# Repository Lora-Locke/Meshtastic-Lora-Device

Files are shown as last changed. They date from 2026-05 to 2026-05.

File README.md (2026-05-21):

# 📡 LoRa Meshtastic Device — lora-locke

> *"What if you could send messages across kilometres of countryside, through forests, over hills,*  
> *with no phone signal, no internet, and no monthly bill?"*  
> That's exactly what this project does. Welcome to the mesh. 🌐

---

## What Is This?

This is an open source, 3D printed handheld LoRa Meshtastic communication node. It was designed and built as part of an **HNC Engineering Design (Unit 4001)** college project, but it turned into something genuinely useful — a pocket sized, off grid communication device that actually works in the real world.

The device is built around the **Seeed XIAO ESP32S3 + Wio SX1262 kit** from The Pi Hut, powered by dual hot swappable 18650 batteries, and housed in a custom designed 3D printed PLA enclosure with a detachable external SMA antenna. It talks to your phone over Bluetooth via the free **Meshtastic app**, and it can communicate with other Meshtastic nodes up to several kilometres away with absolutely no infrastructure whatsoever.

No towers. No SIM card. No subscription. Just radio waves and clever firmware.

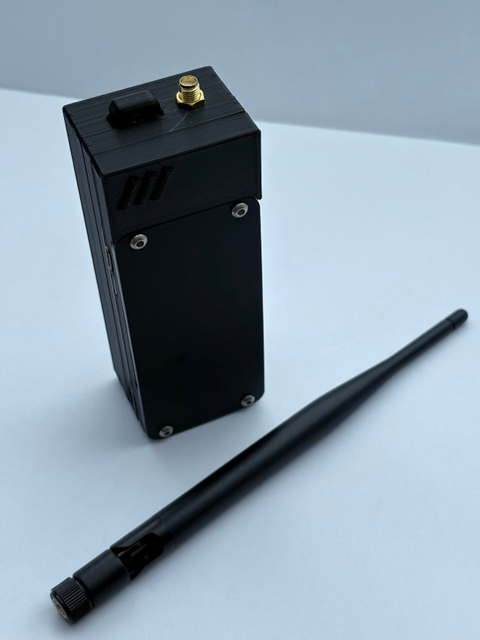
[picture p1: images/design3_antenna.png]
Device with antenna


---

## Why Does This Exist?

Good question. The short answer: because conventional communication infrastructure is fragile.

Mobile networks go down in emergencies. Rural areas have black spots the size of small countries. Events with thousands of people bring networks to their knees. And if you've ever tried to coordinate a hiking group in the middle of nowhere, you'll know that shouting really doesn't scale well beyond about 50 metres.

Meshtastic LoRa devices are a genuinely viable solution for:

- 🏔️ **Outdoor adventures** — hiking, mountain biking, wild camping, expeditions
- 🚨 **Emergency preparedness** — resilient backup comms when infrastructure fails
- 🎪 **Events and festivals** — coordinate teams without relying on congested networks
- 🌍 **Remote IoT deployments** — sensor networks in areas without connectivity
- 🔬 **Experimentation** — because building your own radio network is genuinely cool

This isn't a niche hobbyist toy. As infrastructure resilience becomes more important, decentralised mesh communication networks like Meshtastic represent a genuinely compelling backup safety communication solution. A handful of these devices distributed across a team or community creates a self healing, self extending communication network that requires nothing external to operate.

---

## How Does Meshtastic Work?

Meshtastic uses **LoRa (Long Range)** radio to create a mesh network. Each device acts as both a client and a router — when you send a message, nearby nodes receive it and automatically forward it along until it reaches its destination. The more nodes on the network, the further messages can travel.

Think of it like a game of Chinese whispers, except it actually works and the message arrives intact. 📨

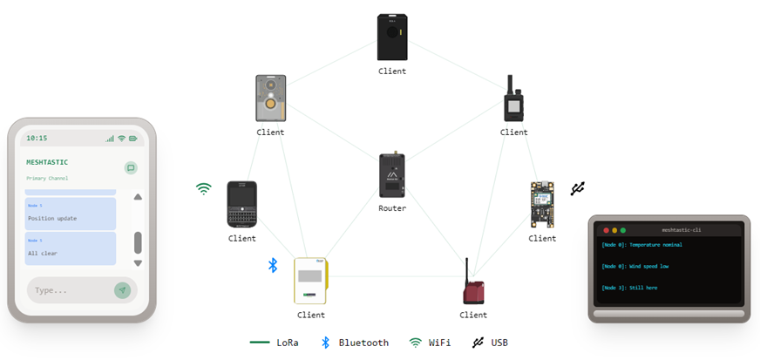
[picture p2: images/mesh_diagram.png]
Meshtastic Mesh Network Diagram


Each node operates on licence exempt frequencies (863–870 MHz in the UK, governed by Ofcom IR 2030 and ETSI EN 300 220), meaning anyone can use one legally without a radio licence.

For the full technical deep dive, the Meshtastic documentation is excellent:
👉 [meshtastic.org/docs/introduction](https://meshtastic.org/docs/introduction/)

---

## Features

- 📡 LoRa mesh communication via Meshtastic (862–930 MHz)
- 📱 Bluetooth app control — no screen needed, your phone is the interface
- 🔋 Dual 18650 hot swappable batteries — up to 30 hours runtime tested
- ⚡ USB-A power output — doubles as a power bank for your phone
- 🔌 USB-C and Micro USB charging inputs
- 🧲 Magnetic battery panel — tool free battery swaps in seconds, one cell at a time
- 📶 Detachable external SMA antenna — remove for pocket carry, attach for max range
- 🔴 Battery indicator LEDs — check charge status at a glance
- 🖨️ Fully 3D printable PLA enclosure
- 🌍 Completely open source hardware and software

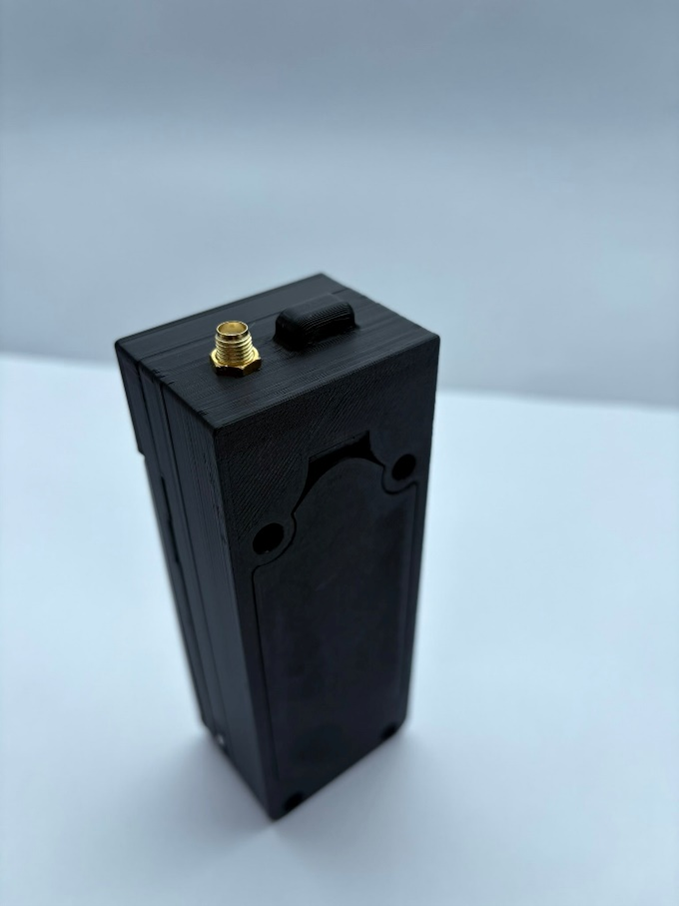
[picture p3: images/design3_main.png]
Device overview


---

## The Design Journey

This project went through three design iterations before landing on the final build. The full engineering process — including SolidWorks CAD models, structural force studies, design considerations across 15 criteria, and a weighted Pugh matrix evaluation — is documented in the accompanying college assignment report.

Here's the short version:

---

### Design 1 — The Brick 🧱

The first attempt. Functional, but at 105mm x 45mm x 50mm it was more portable safe than portable device. The battery board and LoRa module were stacked vertically inside the enclosure, which meant the height was completely impractical. Great as a fixed infrastructure node. Terrible in a pocket. Back to SolidWorks.

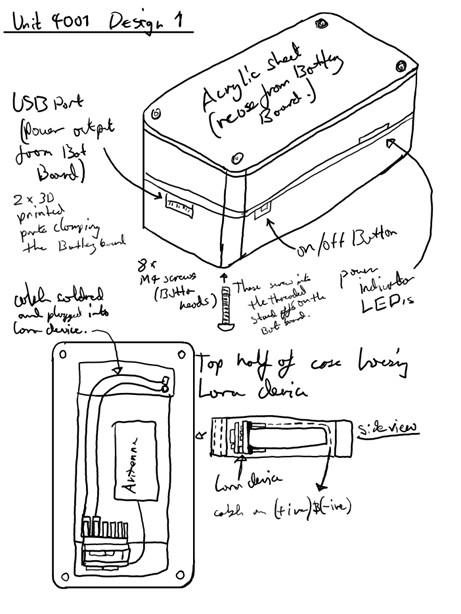
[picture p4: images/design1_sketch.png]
Design 1 Initial Sketch

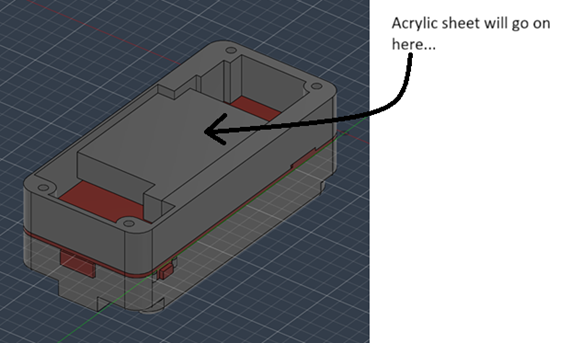
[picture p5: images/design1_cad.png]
Design 1 CAD


---

### Design 2 — Getting There 📐

Rotated the internal layout so the battery board and LoRa module sit side by side instead of stacked on top of each other. Result: 130mm x 50mm x 35mm — noticeably slimmer and much more natural to hold. A SolidWorks Simulation force study was run on this design to simulate drop loading and identify stress concentration points at the enclosure corners, which directly informed the geometry decisions in Design 3.

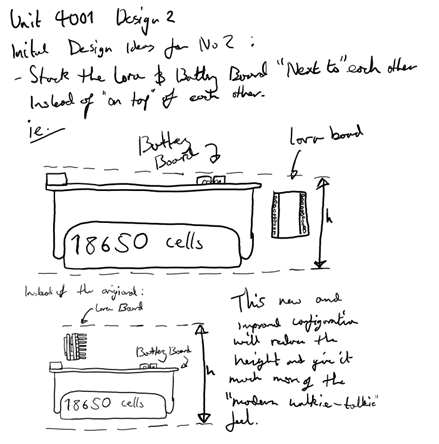
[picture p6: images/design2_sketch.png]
Design 2 Initial Sketch

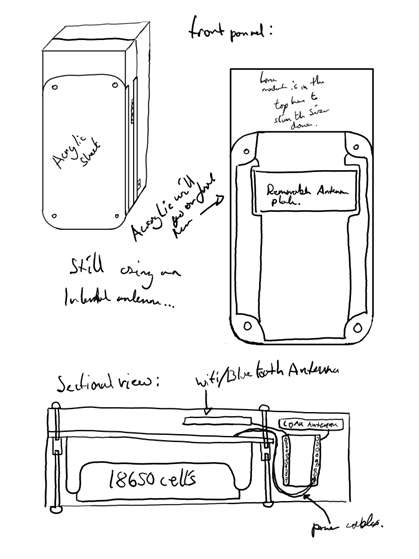
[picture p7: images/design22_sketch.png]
Design 2 Second Sketch

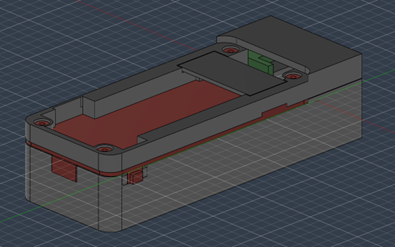
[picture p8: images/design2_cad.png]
Design 2 CAD

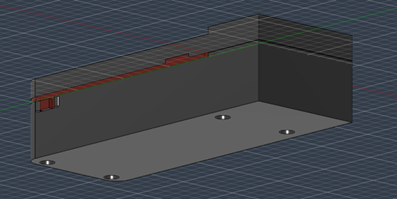
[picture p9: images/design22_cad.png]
Design 2 CAD View 2

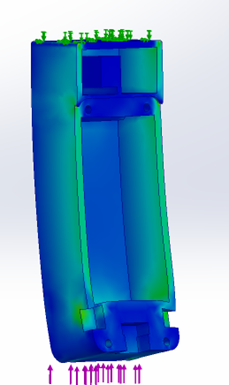
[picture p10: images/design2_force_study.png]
Design 2 Force Study

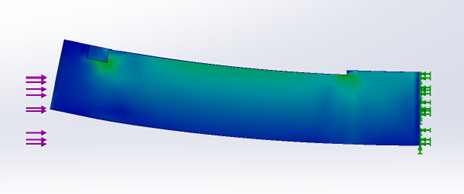
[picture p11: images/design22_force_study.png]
Design 2 Force Study View 2


---

### Design 3 — The One That Actually Works ✅

Same core dimensions as Design 2 but with two targeted improvements that make a significant real world difference:

1. **Detachable external SMA antenna** — remove it when pocketing the device, screw it on when you need maximum RF performance. Best of both worlds.
2. **Magnetic hot swap battery panel** — four neodymium magnets retain the battery cover, meaning you can swap 18650 cells in the field in seconds without any tools. One cell at a time, so you never even have to power the device down.

This is the design documented in this repository. This is the one you should build.

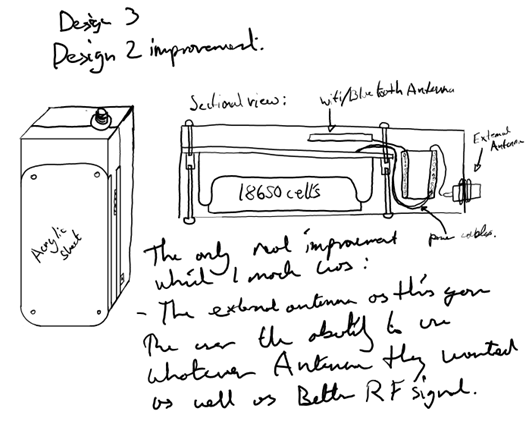
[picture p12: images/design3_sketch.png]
Design 3 Sketch

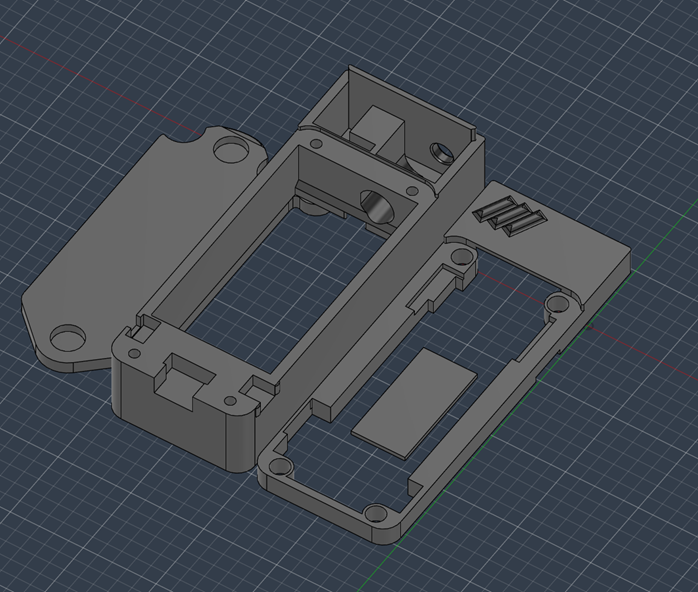
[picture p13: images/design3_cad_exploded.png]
Design 3 CAD Exploded

Design 3 Main Photo
Design 3 With Antenna
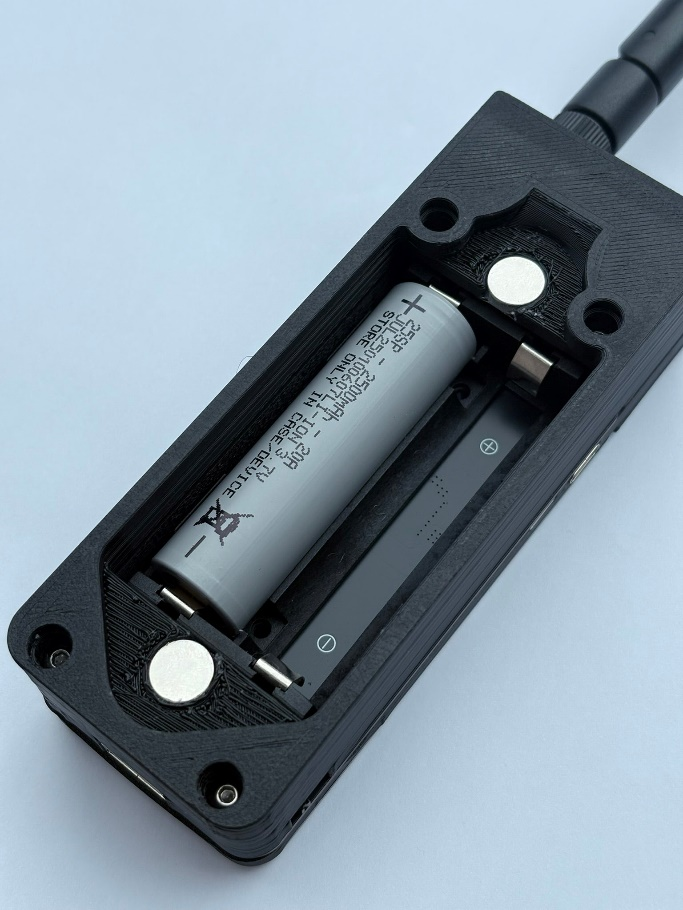
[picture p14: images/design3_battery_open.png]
Design 3 Battery Panel Open

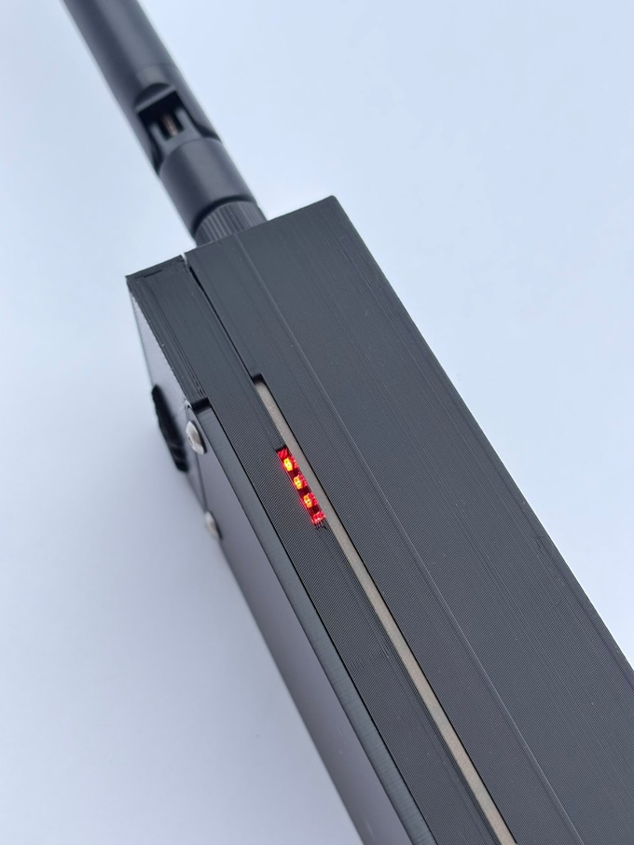
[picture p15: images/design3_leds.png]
Design 3 LED Battery Indicator

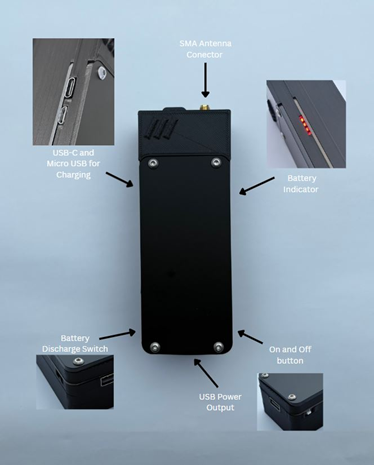
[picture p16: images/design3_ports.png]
Design 3 Ports


---

## What You Need to Build One

### Electronics

| Component | Supplier | Approx Cost |
|---|---|---|
| XIAO ESP32S3 + Wio SX1262 Kit | [The Pi Hut](https://thepihut.com/products/xiao-esp32s3-wio-sx1262-kit-for-meshtastic-lora) | £10.50 |
| 2-Way 18650 Battery Management Board | [The Pi Hut](https://thepihut.com/products/2-way-18650-battery-holder) | £8–£15 |
| 2x 18650 Li-Ion Cells | Any reputable supplier — not included | £5–£15 |
| SMA Female Bulkhead Connector | Amazon / AliExpress | £1–£3 |
| U.FL to SMA Pigtail Cable | Amazon / AliExpress | £1–£3 |
| 868MHz SMA Whip Antenna | Amazon / AliExpress | £2–£5 |
| M4 Button Head Screws x8 | Local hardware store | £1 |
| Neodymium Magnets x4 (~10mm dia) | Amazon / AliExpress | £2–£4 |
| **Total** | | **~£30–£55** |

### Tools and Materials

- FDM 3D printer (any well calibrated machine)
- Matte black PLA filament
- Small Phillips head screwdriver
- Soldering iron and solder
- Wire strippers
- Superglue (for magnets)

---

## How to Print the Enclosure

All STL files are in the `/CAD` folder of this repository.

**Recommended print settings:**

| Setting | Value |
|---|---|
| Material | PLA or PLA+ |
| Layer height | 0.2mm |
| Wall thickness | 2.4mm minimum |
| Infill | 20% honeycomb minimum |
| Supports | Required for some features |
| Orientation | Primary load bearing faces parallel to print bed |

> If you're in a hot climate or leaving the device in a car, use PETG instead of PLA.
> PLA softens at around 55°C which is a bad day for your enclosure. 🌞

---

## How to Flash Meshtastic

The XIAO ESP32S3 + Wio SX1262 kit from The Pi Hut comes **pre-flashed** with Meshtastic firmware straight out of the box. You probably won't need to do anything here at all.

If you do need to update or reflash:

1. Go to 👉 [flasher.meshtastic.org](https://flasher.meshtastic.org)
2. Connect your device via USB-C
3. Select **XIAO ESP32S3** as your device
4. Click Flash and wait about 30 seconds
5. Done. Seriously, that's it.

Full flashing guide with troubleshooting is in `/Firmware/flashing_guide.md`.

---

## How to Use It

1. Insert two 18650 cells into the battery compartment and close the magnetic panel
2. Press the power button on the top of the device
3. Download the **Meshtastic app** on your phone — iOS or Android, it's free
4. Open the app, go to Bluetooth, and pair with your device
   - Default PIN: **123456**
5. Set your region to **EU_868** for UK use
6. Screw on the SMA antenna
7. You're on the mesh 🎉

From the app you can send messages, see other nodes on a map, configure channels, check battery level, and adjust all settings. The device itself needs no further interaction — one button to rule them all.

---

## Assembly Guide

A full step by step assembly guide is in `/Docs/assembly_guide.md`.

The short version:
1. Superglue magnets into pockets in the main body and battery panel — check polarity first!
2. Install SMA bulkhead connector in the top of the front half
3. Stick the WiFi/BLE antenna to the internal plastic plate
4. Solder two 8cm power cables onto the 5V rail of the battery board
5. Fit the battery board into the back half and secure with four M4 screws
6. Slot the XIAO module into the top of the front half, connect power cables, antenna pigtail and WiFi antenna
7. Test before closing — always
8. Bring both halves together, slide in the internal plate, push in the acrylic sheet, drive the remaining four screws
9. Clip on the magnetic battery panel, screw on the antenna, power on 📡

---

## Repository Structure

```
lora-locke/
├── README.md                        — You are here
├── images/                          — All photos and diagrams
├── CAD/
│   ├── README.md                    — Print settings and file info
│   └── Meshtastic Device 3D.stl    — 3D printable enclosure
├── Firmware/
│   └── flashing_guide.md            — How to flash Meshtastic
└── Docs/
    ├── assembly_guide.md            — Full build instructions
    ├── wiring_guide.md              — Power connections
    ├── BOM.md                       — Full bill of materials
    └── PDS.md                       — Original college project design specification
```

---

## Project Context

This project was completed as part of an **HNC Engineering (Level 4) — Unit 4001 Engineering Design** assignment. The brief required the design and development of a sustainable, cost effective product through a structured iterative engineering design process.

If you're a student looking at this as an example — hi 👋 — the key things the assignment covered were:

- Product Design Specification (PDS) with stakeholder analysis
- Project planning with Gantt chart and Critical Path Analysis
- Three iterative design concepts modelled in SolidWorks
- Structural analysis using SolidWorks Simulation force study
- Design evaluation using a weighted Pugh matrix across 15 criteria
- Design considerations covering material, lifecycle, repairability, sustainability, ergonomics, standards compliance, and more
- A formal engineering design report

The full written assignment and design specification are included in the `/Docs` folder for reference.

---

## Licence

This project is released under the **MIT Licence** — do whatever you want with it, just give a nod to the original. See `LICENSE` for the full terms.

The Meshtastic firmware is a completely separate open source project — full credit and attribution to the Meshtastic team and the incredible community behind it.
👉 [meshtastic.org](https://meshtastic.org)

---

## A Note on Safety Communication

Meshtastic is not a replacement for emergency services. If someone is in danger, call 999.

What it genuinely is useful for is **resilient backup communication** in situations where conventional infrastructure is unavailable, degraded, or congested. A small network of Meshtastic devices provides an infrastructure independent communication layer that costs very little to deploy, requires no ongoing subscription or maintenance, and works anywhere there's line of sight or a mesh of nodes.

For event safety teams, mountain rescue support groups, remote work crews, and outdoor enthusiasts — it's worth thinking about seriously.

---

*Built with SolidWorks, printed in PLA, powered by 18650s, and fuelled by an unhealthy interest in radio waves. 📡*

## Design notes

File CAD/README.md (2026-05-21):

# CAD Files 🖨️

This folder contains the 3D printable STL file for the 
LoRa Meshtastic device enclosure.

---

## Files

| File | Description |
|---|---|
| `Meshtastic Device 3D.stl` | Complete enclosure — contains both the front and back halves of the case, the internal plastic plate, and the magnetic battery panel |

---

## Print Settings

| Setting | Recommended Value |
|---|---|
| Material | PLA or PLA+ |
| Layer height | 0.2mm |
| Wall thickness | 2.4mm minimum (3 perimeter passes) |
| Infill | 20% honeycomb minimum |
| Supports | Yes — required for some features |
| Print orientation | Primary load bearing faces parallel to print bed |

---

## Notes

- Matte black PLA is recommended for the best finish — 
  it hides layer lines effectively and looks great
- If you're in a hot climate or the device will be left in a car, 
  consider PETG instead — PLA softens at around 55°C which is 
  not ideal on a hot sunny day 🌞
- All parts are included in the single STL file — 
  import it into your slicer and arrange the parts on the build plate
- Recommended slicers: PrusaSlicer, Cura, Bambu Studio

---

## Hardware Required

Once printed you'll need the following to complete the build:

- M4 button head screws x8
- Neodymium magnets x4 (approx 10mm diameter)
- Superglue (for securing magnets)

Full assembly instructions are in the `/Docs` folder. 
Full BOM is in `/Docs/BOM.md`.

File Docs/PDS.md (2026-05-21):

# Product Design Specification (PDS) 📄

> This PDS was produced as part of an HNC Engineering Design (Unit 4001) 
> college assignment. It represents the initial design brief created at 
> the start of the project which all three designs were measured against. 
> If you're a student looking at this as an example — hi 👋 — feel free 
> to use this as a reference for how to structure your own PDS, 
> but make sure you write your own version in your own words!

---

## Product Information

| Field | Detail |
|---|---|
| Designer | Theo Locke |
| Product Name | Long Range Communication Device using Meshtastic (LoRa) |
| Date | March 2026 |
| Project Context | HNC Engineering Design — Unit 4001 |

---

## What I Am Trying to Achieve

The goal of this project is to design and build a case which can house 
a LoRa Meshtastic radio module with a built in battery, small enough 
to fit in a pocket and be carried around on a daily basis for 
off grid communication. An additional goal is the possibility of 
the device also functioning as a portable battery pack for charging 
other devices such as a smartphone.

The enclosure must be made from as sustainable and environmentally 
friendly a material as possible, with PLA identified as a strong 
candidate due to its bio-based origin from corn starch.

---

## How LoRa Mesh Networks Work

LoRa (Long Range) is a wireless communication method that allows 
devices to send small messages over several kilometres whilst using 
very little power. Rather than relying on mobile networks, WiFi, 
or the internet, LoRa devices communicate directly with each other 
using radio waves on licence exempt frequencies.

LoRa mesh networks enable long range, off grid communications by 
allowing individual LoRa nodes to relay messages to each other 
through a series of hops — from one node to another — until the 
message reaches its destination.

> *"Meshtastic is a project that enables you to use inexpensive LoRa 
> radios as a long range off-grid communication platform in areas 
> without existing or reliable communications infrastructure. 
> This project is 100% community driven and open source!"*
> — [meshtastic.org](https://meshtastic.org/docs/introduction/)

Meshtastic is the firmware used by this device to join and operate 
within the mesh network. Full documentation is available at:
👉 [meshtastic.org/docs/introduction](https://meshtastic.org/docs/introduction/)

---

## Core Requirements

These are the non-negotiable requirements the final design must meet:

| # | Requirement | Reason |
|---|---|---|
| 1 | Device must be pocketable — fit in an average size pocket | Everyday carry use case |
| 2 | Easy to charge via a standard connector, ideally with fast charge support | Convenience and accessibility |
| 3 | Total cost below £50 as a kit or pre-built product | Accessibility for hobbyists and makers |
| 4 | Universal power and data port if no built in battery | Interoperability |
| 5 | Minimum 5km communication range with mesh hopping | Core functional requirement |
| 6 | Must support Meshtastic firmware | Core functional requirement |
| 7 | Enclosure material must be as sustainable as possible | Brief requirement |

---

## Optional Features and Possible Extras

These are desirable but not essential — nice to haves that would 
add value if achievable within the design constraints:

- MagSafe compatibility for attaching to the back of an iPhone
- Small enough to hold comfortably in one hand or attach to the 
  back of a phone
- Internal or external antenna depending on the chosen module and 
  design iteration
- Hot swappable battery — either for end of life replacement or 
  field swapping without powering down

> **Note:** The hot swap battery feature made it into the final 
> Design 3 via a magnetic battery panel — one of the most satisfying 
> moments of the whole project. 🧲

---

## Standards and Regulatory Requirements

| Standard | Description |
|---|---|
| ETSI EN 300 220 | UK and EU standard governing short range radio devices operating at 868MHz |
| Ofcom IR 2030 | UK Interface Requirement governing licence exempt LoRa operation |
| LoRa Alliance Network Protocol | Governs the LoRaWAN protocol and interoperability between devices |

---

## Operational Parameters

| Parameter | Value |
|---|---|
| Frequency range | 863 – 870 MHz |
| Regulatory framework | Ofcom IR 2030, ETSI EN 300 220 |
| Firmware | Meshtastic |
| Connectivity | Bluetooth Low Energy (BLE) to smartphone |

---

## Material Notes

PLA (Polylactic Acid) was identified early in the project as the 
preferred enclosure material. It is derived from renewable resources 
such as corn starch, making it significantly more sustainable than 
petroleum based alternatives such as ABS or PETG. It is also the 
most widely used FDM printing material, keeping the barrier to 
community manufacture as low as possible.

Recycled PLA was also considered and is documented as a preferred 
option where available in the full design considerations section 
of the assignment report.

---

## How Did the Final Design Measure Up?

Looking back at the PDS from the end of the project, here is how 
Design 3 — the final chosen design — performed against each requirement:

| Requirement | Met? | Notes |
|---|---|---|
| Pocketable | ✅ Partially | Fits jacket and cargo pockets comfortably. Trouser pockets are tight at 130mm length |
| Easy to charge | ✅ Yes | USB-C and Micro USB inputs, plus USB-A output |
| Under £50 | ✅ Yes | BOM cost £24–£50 depending on sourcing |
| Universal port | ✅ Yes | USB-C on all designs |
| 5km+ range | ✅ Yes | External SMA antenna on Design 3 improves range significantly |
| Meshtastic compatible | ✅ Yes | XIAO kit comes pre-flashed |
| Sustainable material | ✅ Yes | Matte black PLA enclosure throughout |
| Hot swap battery | ✅ Yes | Magnetic panel on Design 3 enables tool free hot swap |

---

## References

[1] Meshtastic, "Meshtastic Introduction," [Online]. 
Available: https://meshtastic.org/docs/introduction/. 
[Accessed 17 03 2026].

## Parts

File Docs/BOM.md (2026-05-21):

# Bill of Materials 📋

Full components list for the LoRa Meshtastic device.
All components used in this build were sourced from The Pi Hut 
and standard UK suppliers.

## Core Electronics

| Component | Description | Supplier | Approx Cost |
|---|---|---|---|
| XIAO ESP32S3 + Wio SX1262 Kit | Main LoRa module, pre-flashed with Meshtastic | [The Pi Hut](https://thepihut.com/products/xiao-esp32s3-wio-sx1262-kit-for-meshtastic-lora) | £10.50 |
| 2-Way 18650 Battery Management Board | Handles charging, protection, and USB output | [The Pi Hut](https://thepihut.com/products/2-way-18650-battery-holder) | £8–£15 |
| 18650 Li-Ion Cells x2 | 2500–3500mAh recommended — not included | Any reputable supplier | £5–£15 |

## Antenna Components

| Component | Description | Supplier | Approx Cost |
|---|---|---|---|
| SMA Female Bulkhead Connector | Mounts in top of enclosure | Amazon / AliExpress | £1–£3 |
| U.FL to SMA Pigtail Cable | Connects LoRa module to SMA connector | Amazon / AliExpress | £1–£3 |
| 868MHz SMA Whip Antenna | External antenna, screws onto SMA connector | Amazon / AliExpress | £2–£5 |
| WiFi / BLE Antenna | Small stick-on antenna for XIAO module | Included with XIAO kit | £0 |

## Enclosure Hardware

| Component | Description | Supplier | Approx Cost |
|---|---|---|---|
| M4 Button Head Screws x8 | Holds enclosure halves together | Local hardware store | £1 |
| Neodymium Magnets x4 (approx 10mm dia) | Retains magnetic battery panel | Amazon / AliExpress | £2–£4 |
| Superglue | For securing magnets into pockets | Local hardware store | £1 |

## Wiring

| Component | Description | Approx Cost |
|---|---|---|
| Red wire — approx 8cm | 5V positive connection | £0 (off a reel) |
| Black wire — approx 8cm | GND connection | £0 (off a reel) |
| Header pins x2 | Clean plug-in connection to XIAO | £1 |

## 3D Printing

| Component | Description | Approx Cost |
|---|---|---|
| Black PLA Filament | Matte finish recommended | £1–£2 per print |

## Total Estimated Cost

| Scenario | Cost |
|---|---|
| Self-build (sourcing cheaply) | £24 – £35 |
| Self-build (standard pricing) | £35 – £50 |

---

## Notes

- 18650 cells are not included and must be sourced separately — 
  use reputable brands only, avoid unbranded cells from unknown suppliers
- The XIAO ESP32S3 + Wio SX1262 kit comes pre-flashed with Meshtastic 
  firmware so no additional flashing is required out of the box
- All electronic components sourced from The Pi Hut carry their own 
  compliance certifications — they are CE and UKCA marked 
  where applicable
- STL files for the 3D printed enclosure are in the `/CAD` folder 
  of this repository

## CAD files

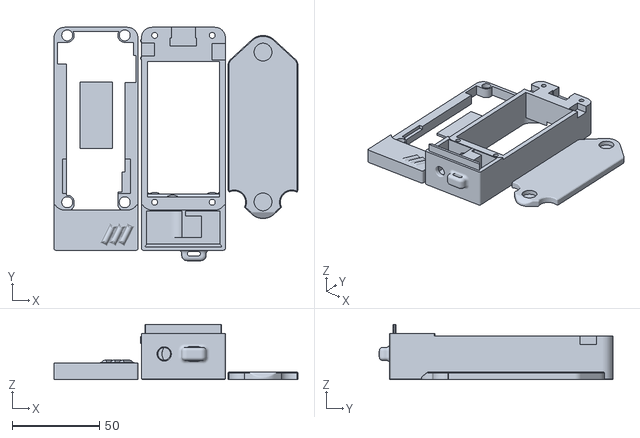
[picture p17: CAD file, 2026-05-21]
CAD/Meshtastic Device 3D.stl
139.5 x 133.5 x 31.7

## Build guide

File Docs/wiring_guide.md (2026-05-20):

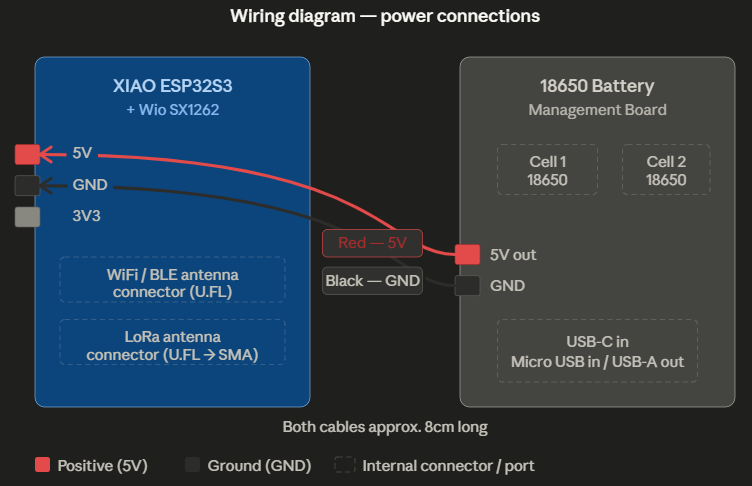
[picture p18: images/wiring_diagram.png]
Wiring Diagram


# Wiring Guide ⚡

The wiring for this device is extremely simple — 
just two cables connecting the battery board to the LoRa module.
That's it. Seriously.

## Power Connections

Solder two cables approximately **8cm long** onto the **5V power rail** 
of the 18650 battery management board:

| Wire | From | To | Colour |
|---|---|---|---|
| Positive | 5V out on battery board | 5V pin on XIAO ESP32S3 | Red |
| Ground | GND on battery board | GND pin on XIAO ESP32S3 | Black |

Attach **header pins** to the XIAO end of both cables so they plug 
directly into the XIAO module's pin headers cleanly and can be 
unplugged easily for servicing.

⚡ **Double check polarity before connecting.** 
Positive to positive, negative to negative. 
Reversing this will damage the XIAO module instantly.

## Antenna Connections

| Connection | From | To |
|---|---|---|
| LoRa antenna | U.FL port on Wio SX1262 | SMA bulkhead connector on enclosure top |
| WiFi/BLE antenna | U.FL port on XIAO ESP32S3 | Antenna stuck to internal plastic plate |

The U.FL connectors are small and delicate — press straight down 
until you feel a click. Never force at an angle.

## Wiring Diagram

See the diagram in the repository images folder for a visual 
reference of all connections.

## Notes

- Keep cables to approximately 8cm — long enough to reach comfortably, 
  short enough not to bunch up inside the case
- The WiFi/BLE antenna sticks onto the internal plastic plate 
  which sits inside the front half of the case
- The LoRa antenna connects via a U.FL to SMA pigtail cable 
  which routes to the SMA bulkhead connector on the top of the enclosure
- No other wiring is required — all other connections 
  (USB charging, power button, battery indicator LEDs) are handled 
  internally by the battery management board itself

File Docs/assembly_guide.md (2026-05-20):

# Assembly Guide 🔧

This guide walks you through assembling your LoRa Meshtastic device 
from scratch. It's not complicated, but read through the whole thing 
before you start so you know where you're headed. 
Nobody likes getting to step 6 and realising they forgot step 2.

Photos of the assembly process will be added to this folder soon.

---

## Before You Start

Make sure you have everything from the BOM ready before you begin. 
See [BOM.md](BOM.md) for the full components list and where to get them.

You'll also need your 3D printed enclosure parts ready. 
Print settings and STL files are in the `/CAD` folder of this repository.

### Tools Required

- Soldering iron and solder
- Wire strippers
- Small Phillips head screwdriver
- Superglue
- Needle nose pliers (helpful but not essential)
- Multimeter (recommended for checking connections before closing up)

---

## Parts Overview

Before you start, lay out your printed parts and familiarise yourself 
with them:

- **Back half of case** — houses the 18650 battery board and cells
- **Front half of case** — houses the XIAO LoRa module and internal plate
- **Internal plastic plate** — sits inside the front half, 
  holds the WiFi/BLE antenna
- **Magnetic battery panel** — the external cover for the battery 
  compartment, retained by magnets
- **Acrylic sheet** — sandwiches everything together on the front half, 
  secured by four screws

---

## Step 1 — Solder the Power Cables

Start by soldering two cables onto the **5V power rail** of the 
18650 battery management board. Each cable should be approximately 
**8cm long** — long enough to reach the XIAO module comfortably 
once everything is inside the case without being so long they 
become a tangled nightmare.

Once soldered, attach header pins to the free ends of the cables 
so they can plug directly into the XIAO ESP32S3 power input. 
This keeps the connection clean and means the board can be 
unplugged easily if you ever need to service it.

⚡ **Double check your polarity before moving on.** 
Positive to positive, negative to negative. 
Reversing this will kill the XIAO module instantly 
and there's no recovering from that. Ask me how I know. 🙃

---

## Step 2 — Superglue the Magnets

Before anything goes into the case, superglue the four neodymium 
magnets into their pockets in the **back half of the case** and into 
the **magnetic battery panel**.

⚠️ **Critical:** Test the polarity of each magnet before gluing. 
The magnets in the case and the panel need to **attract** each other. 
If you glue them in the wrong way round the panel will repel itself 
off the case which is both useless and embarrassing.

Hold each magnet in place for 30 seconds after applying glue 
and leave to fully cure before continuing.

---

## Step 3 — Install the SMA Connector

Press the SMA bulkhead connector into the hole at the top of the 
**front half of the case** and secure it with its locking nut. 
Firm but not overtightened — you're threading into printed plastic, 
not cast iron.

---

## Step 4 — Prepare the Internal Plastic Plate

Stick the **WiFi/BLE antenna** onto the internal plastic plate. 
This plate sits inside the front half of the case and the antenna 
lives on it, tucked neatly inside the enclosure.

Set this aside for now — it goes in during final assembly.

---

## Step 5 — Assemble the Back Half

Place the **18650 battery management board** into the back half 
of the case, routing the two power cables you soldered in Step 1 
toward the top of the case where the XIAO module will sit.

Insert your **18650 cells** into the battery holder.

Secure the back half of the case with the **first four screws**. 
These hold this half of the assembly together.

---

## Step 6 — Install the XIAO LoRa Module

Slot the **XIAO ESP32S3 + Wio SX1262 module** into its pocket 
at the top of the front half of the case.

Then:

1. Route the two power cables from the battery board and 
   plug them into the XIAO module header pins
2. Connect the **U.FL antenna extension to SMA pigtail** 
   to the LoRa antenna port on the Wio SX1262 module — 
   press it down firmly and straight until you feel a click, 
   this connector is small and does not appreciate being 
   forced at an angle
3. Plug the **WiFi/BLE antenna** cable onto its connector 
   on the XIAO module

---

## Step 7 — Test Before Closing

Before you button everything up, do a quick sanity check:

1. Press the power button on the battery board
2. Check the LED indicators light up
3. Open the Meshtastic app on your phone and confirm 
   the device appears over Bluetooth

If it works, great — power it back off and move to Step 8. 
If it doesn't, now is a vastly better time to find out 
than after you've put all the screws in.

---

## Step 8 — Close the Case

Bring the front half and back half of the case together, 
making sure all cables are routed neatly inside and nothing 
is being pinched at the join.

Slide the **internal plastic plate** (with the WiFi/BLE antenna 
attached) into its slot on the front of the case.

Push the **acrylic sheet** into place on the front of the case — 
this sandwiches the internal plate and antenna in position, 
holding everything securely without the need for additional fixings.

Finally, drive the remaining **four screws** through the acrylic sheet 
and front half of the case. These screws secure the whole assembly 
and hold the cables and antenna routing in place.

---

## Step 9 — Attach the Battery Panel and Antenna

Clip the **magnetic battery panel** over the battery compartment — 
the magnets will pull it into place automatically.

Screw on your **SMA whip antenna**.

Power on, open the Meshtastic app, set your region to **EU_868** 
for UK use, and you're on the mesh. 📡

---

## Tips and Common Mistakes

- **Check magnet polarity before gluing** — seriously, do this
- **Don't overtighten the screws** — printed threads strip easily, 
  snug is enough
- **Keep power cables to ~8cm** — too long and they'll bunch up 
  and cause problems when closing the case
- **Test before closing** — always, every time, no exceptions
- **Set your region in the app** — EU_868 for UK, 
  check Meshtastic docs for your region if you're elsewhere

---

## Need Help?

Open an issue on this repository and we'll help where we can. 
The Meshtastic Discord community is also extremely active and helpful — 
link in the [firmware guide](../Firmware/flashing_guide.md).

---

*Assembly photos coming soon — the device will be disassembled 
and photographed step by step to accompany this guide.* 📸

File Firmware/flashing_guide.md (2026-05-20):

# Flashing Meshtastic Firmware 📡

The XIAO ESP32S3 + Wio SX1262 kit comes pre-flashed with Meshtastic 
firmware straight out of the box, so in most cases you won't need to 
do anything here at all. However if you need to update to a newer version 
of Meshtastic, or if something has gone wrong and you need to reflash, 
this guide will walk you through it.

The whole process takes about 2 minutes and requires no technical knowledge 
beyond being able to plug in a USB cable. Which hopefully you can manage. 🔌

---

## What You Need

- Your LoRa device
- A USB-C cable
- A computer running Google Chrome or Microsoft Edge
  (Firefox won't work here — the web flasher uses Web Serial API 
  which Firefox doesn't support yet, sorry Firefox fans)
- An internet connection

---

## Step by Step

### 1. Connect your device
Plug your device into your computer using a USB-C cable. 
You don't need to power it on first, just plug it in.

### 2. Open the Meshtastic Web Flasher
Go to 👉 [flasher.meshtastic.org](https://flasher.meshtastic.org)

This is the official Meshtastic web flasher tool. 
It runs entirely in your browser and no software installation is required.

### 3. Select your device
From the device dropdown menu select:

**Seeed Studio XIAO S3**

If you don't see this option, make sure you're using Chrome or Edge 
and that your USB-C cable supports data transfer 
(some cheap cables are charge only — classic).

### 4. Select the firmware version
The flasher will show you the latest stable release of Meshtastic. 
Unless you have a specific reason to use an older version, 
always go with the latest stable release.

### 5. Flash the device
Click the **Flash** button.

The flasher will ask you to select a serial port — 
a popup will appear showing available ports. 
Select the one that corresponds to your device 
(it will usually show up as something like COM3 on Windows 
or /dev/ttyUSB0 on Linux/Mac).

The flashing process takes around 30 seconds. 
You'll see a progress bar. Don't unplug the device during this time 
or you'll have a bad time.

### 6. Done!
Once complete the device will automatically reboot with the new firmware. 
You're ready to go.

---

## Setting Up the Meshtastic App

Once your device is flashed and powered on:

1. Download the **Meshtastic app** on your phone
   - iOS: [App Store](https://apps.apple.com/app/meshtastic/id1586432531)
   - Android: [Google Play](https://play.google.com/store/apps/details?id=com.geeksville.mesh)

2. Open the app and tap **+** to add a new device

3. Select your device from the Bluetooth list

4. Enter the default PIN: **123456**

5. You're on the mesh! 🎉

From the app you can configure your device name, set your region 
(make sure to set this to **EU_868** for UK use to ensure you're 
operating on the correct frequency band), 
join or create channels, and send messages to other nodes.

---

## Troubleshooting

**My device isn't showing up in the flasher**
- Try a different USB-C cable — data only cables are a common culprit
- Make sure you're using Chrome or Edge
- Try a different USB port on your computer

**The flash failed halfway through**
- Don't panic. Just try again from Step 3.
- If it keeps failing, try holding the BOOT button on the XIAO module 
  while plugging in the USB cable to force it into bootloader mode

**My device isn't connecting to the app after flashing**
- Make sure you've set your region in the app on first setup
- Try restarting both the device and your phone's Bluetooth

---

## Further Help

The Meshtastic community is large, active, and very helpful.
If you're stuck, the best places to get help are:

- 📖 [Meshtastic Documentation](https://meshtastic.org/docs/)
- 💬 [Meshtastic Discord](https://discord.gg/ktMAKGBnBs)
- 🐙 [Meshtastic GitHub](https://github.com/meshtastic/Meshtastic-device)

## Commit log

2026-05-20 Create flashing_guide.md
    A guide on how to port the firmware across from your computer to the lora device.
2026-05-20 Create assembly_guide.md
    General assembly guide
2026-05-20 Create wiring_guide.md
    Wiring diagram...
2026-05-21 Create BOM.md
    Bill of materials up to date
2026-05-21 Create CAD
    CAD file created
2026-05-21 Create CAD
